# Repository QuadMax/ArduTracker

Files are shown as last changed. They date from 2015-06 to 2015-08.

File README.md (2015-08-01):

# ArduTracker

The ArduTracker is a light weight, easy to build FPV Tracker. It uses the downlink of the audio channel from the Transmitter as telemetry link. But this project is different from most others. ArduTracker is a continuous 360° degree Tracker with a special hinge. This [Video](https://vimeo.com/3991479) shows it best.

***

##[Wiki](https://github.com/QuadMax/ArduTracker/wiki) --||-- [RoadMap](https://github.com/QuadMax/ArduTracker/wiki/RoadMap)
***

###Milestone [0.9.0]
Today the compass could be implemented. This take us a step closer to a stable Version that has got all features.
The system´s components could be tested succesfully each by their own.
A whole system test comes soon.
* **This is new:**
 * implemented compass

###Milestone [0.8.1]
We are close leaving BETA! Heureka.
* **This is new:**
* The pcb design have been reworked. Now we got a groundstation that could power up 5 more devices. With 35um copper thickness it could bear 3 Ampere or 4.5 Ampere with 70um copper thickness.
* Furthermore the code got a rework too.
  * implemented cesco1´s PSK modem instead FSK
  * implemented 270 degree servos
  * implemented display / Menu / buttons
  * implemented servo invert with jumper on the uno shield

### Milestone [0.1.1]
* New pcb design with power distribution. 
  Now you could power up 3 more devices of your ground station with the pcb. Up to 2.5 Ampere. with 35um copper thickness.

### Milestone [0.1.0]
* pcb design first try

### Milestone [0.0.1]
* released Alpha

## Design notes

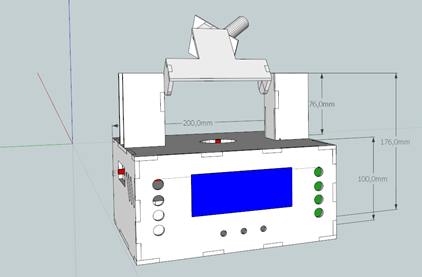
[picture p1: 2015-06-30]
Hardware/Box-all_in_one/big_box.png

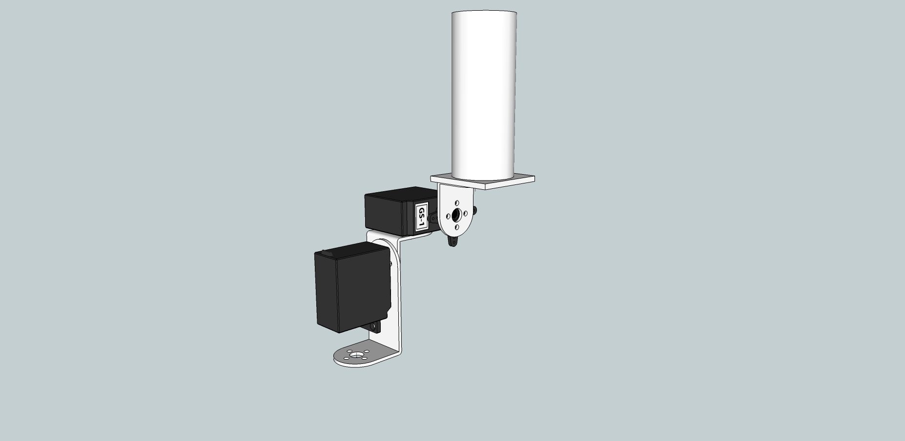
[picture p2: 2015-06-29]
Hardware/Box-minimal/tracker.jpg

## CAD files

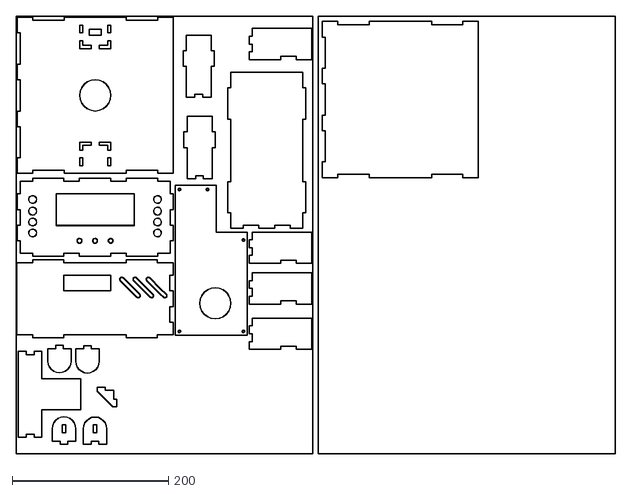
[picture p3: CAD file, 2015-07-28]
Hardware/Box-all_in_one/big_box.dxf
767.4 x 560.0

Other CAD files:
Hardware/Box-all_in_one/tracker 0.1.9.6.skp

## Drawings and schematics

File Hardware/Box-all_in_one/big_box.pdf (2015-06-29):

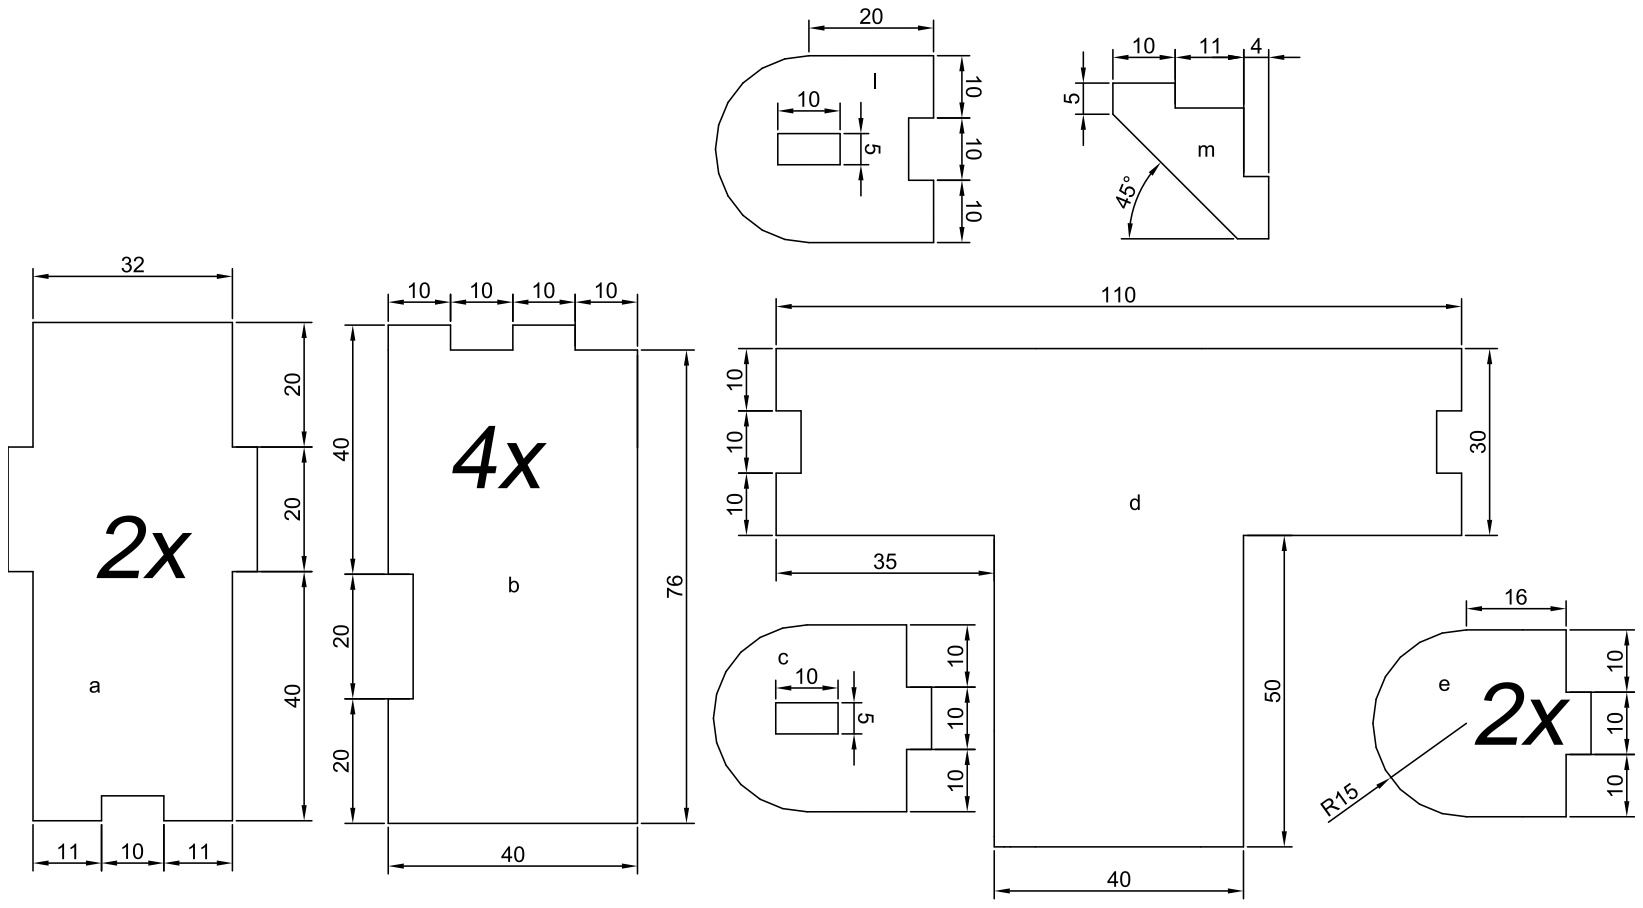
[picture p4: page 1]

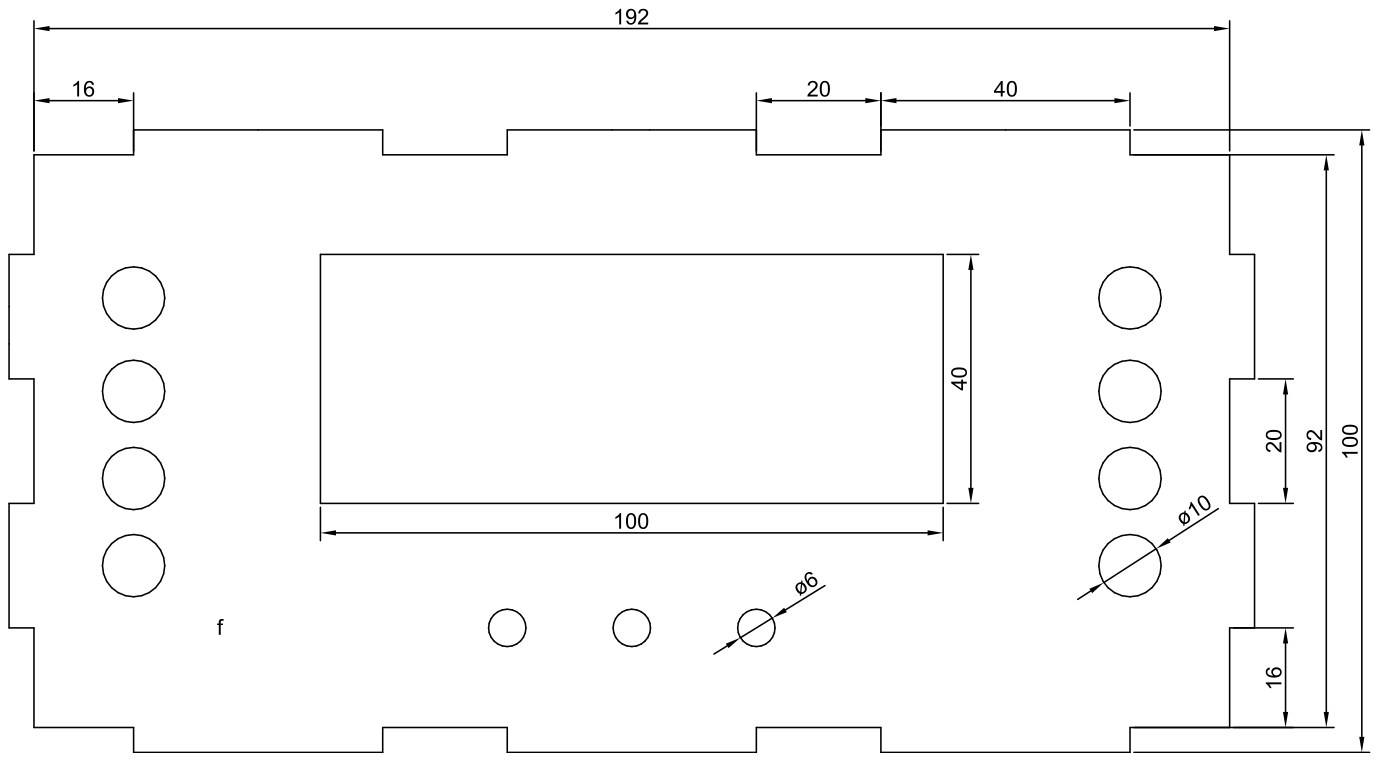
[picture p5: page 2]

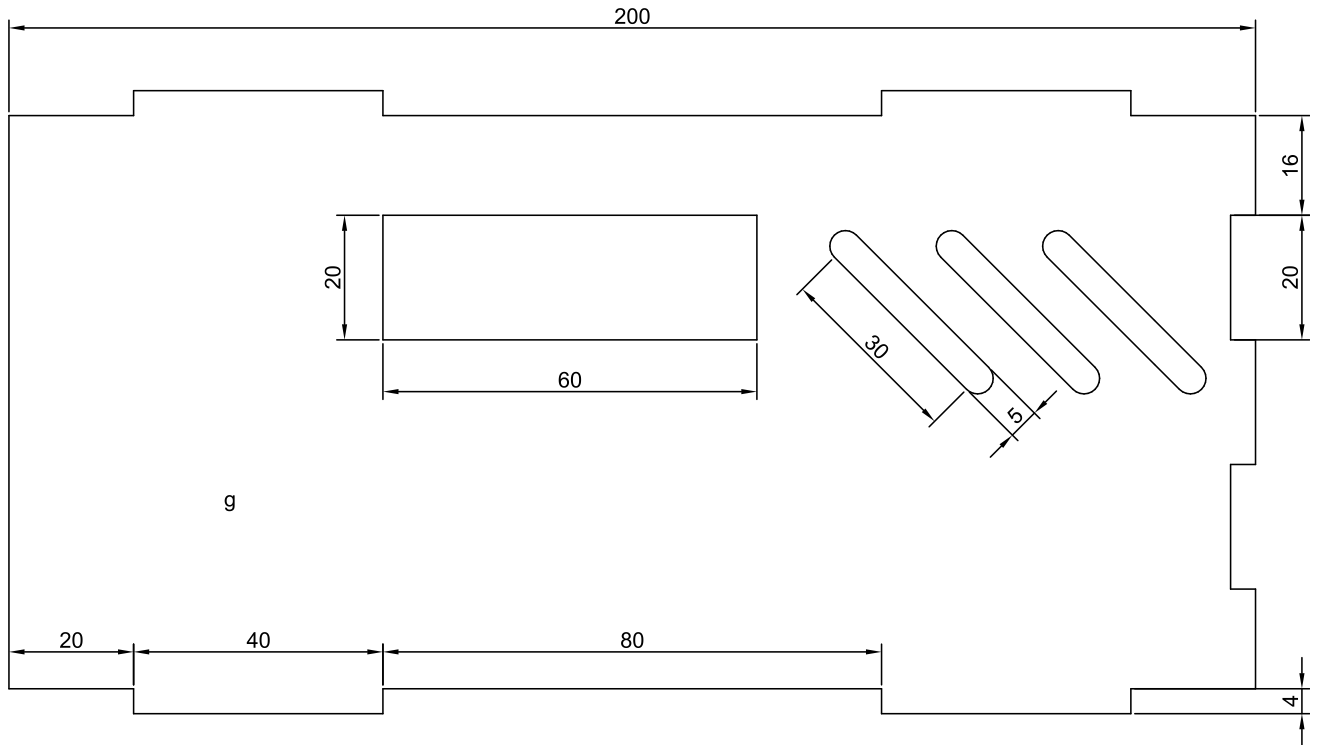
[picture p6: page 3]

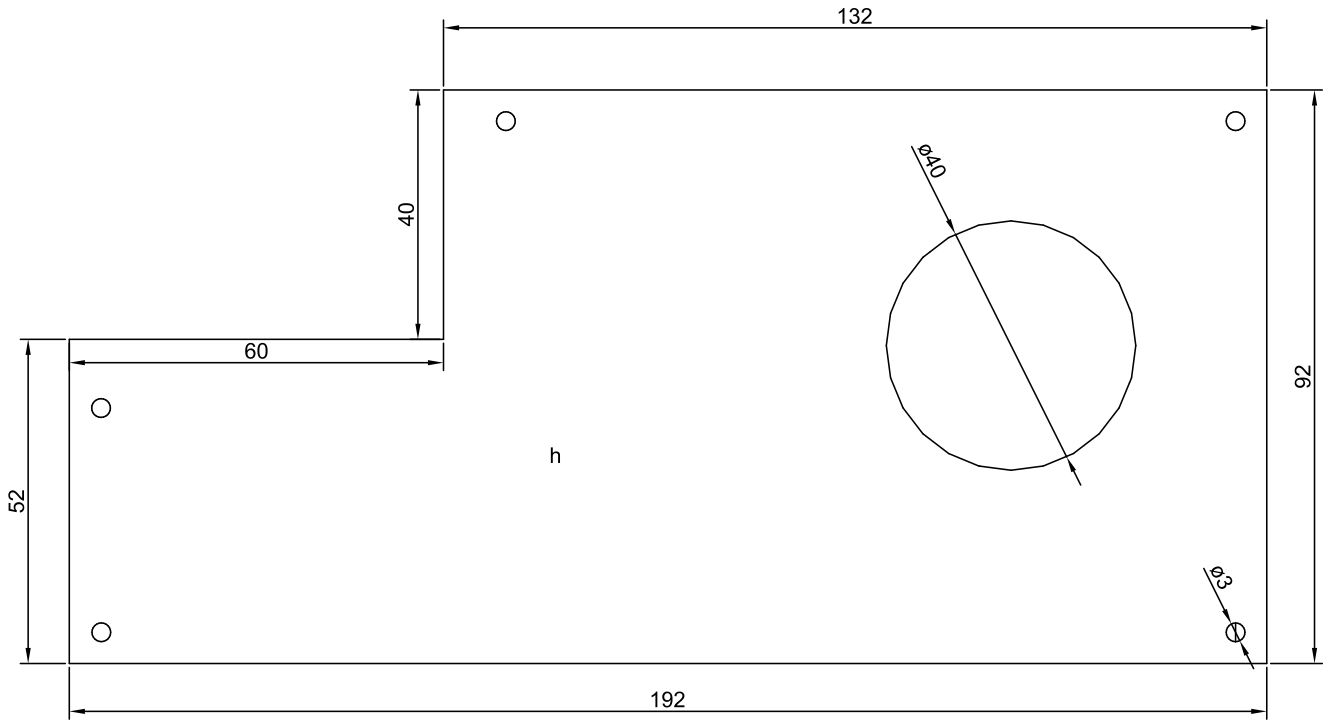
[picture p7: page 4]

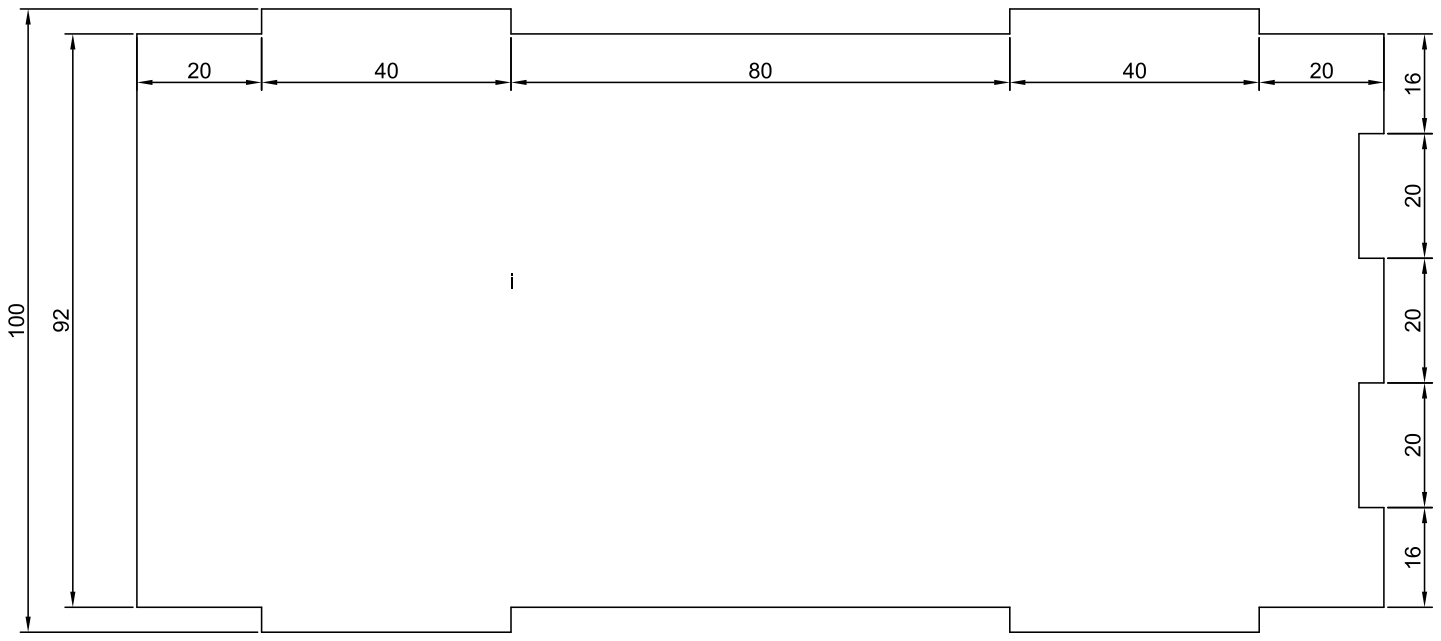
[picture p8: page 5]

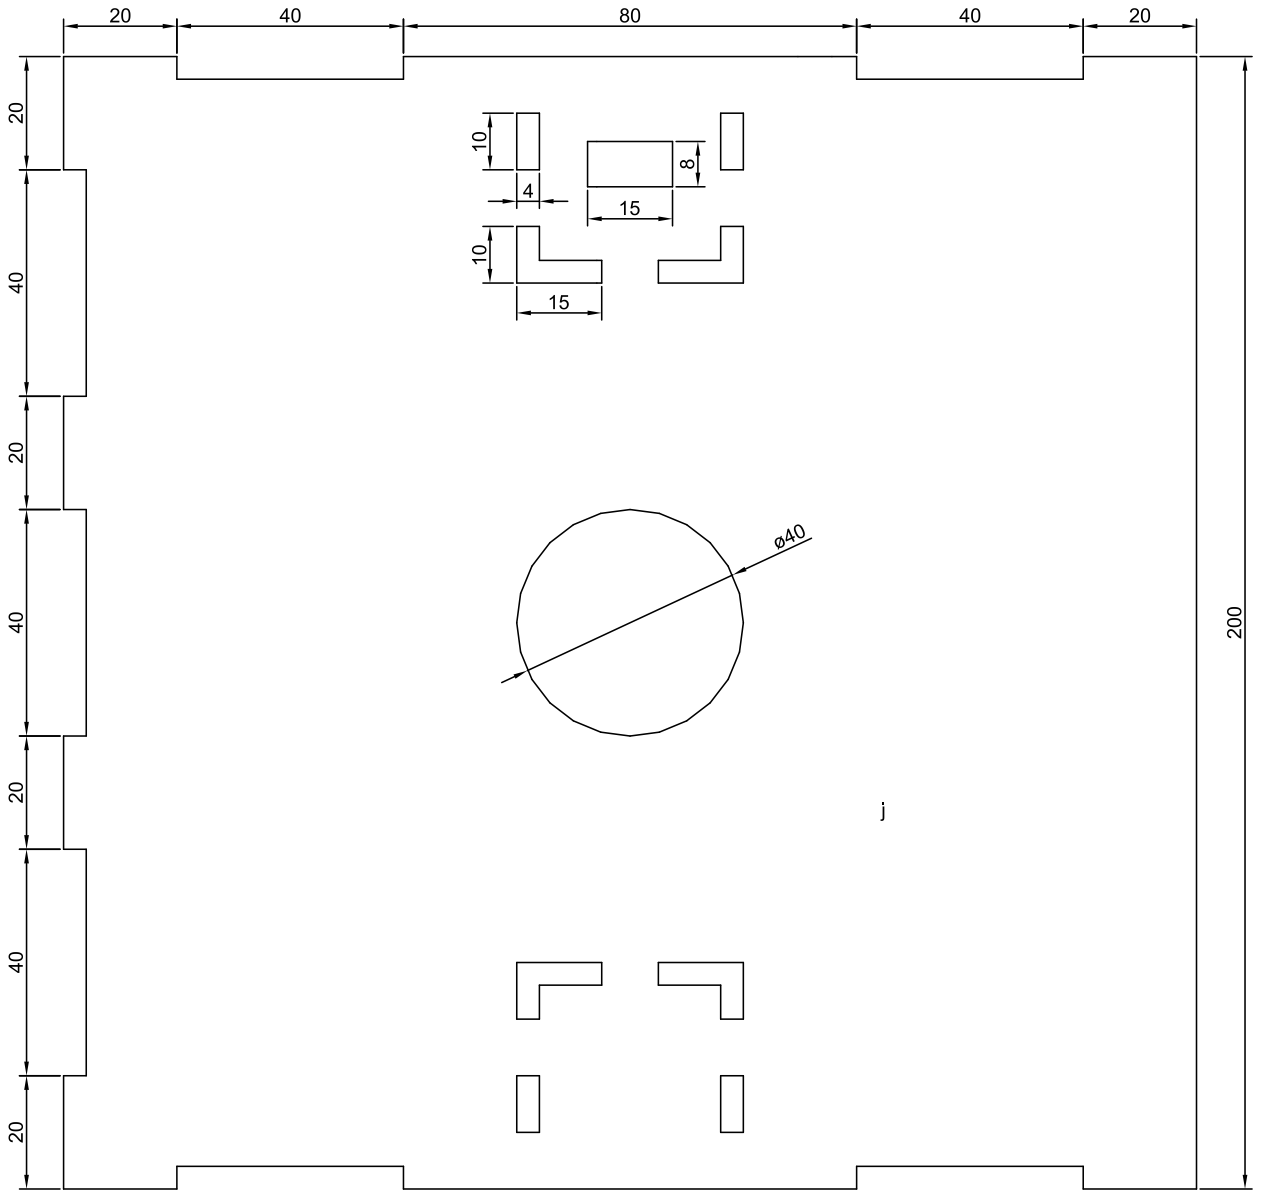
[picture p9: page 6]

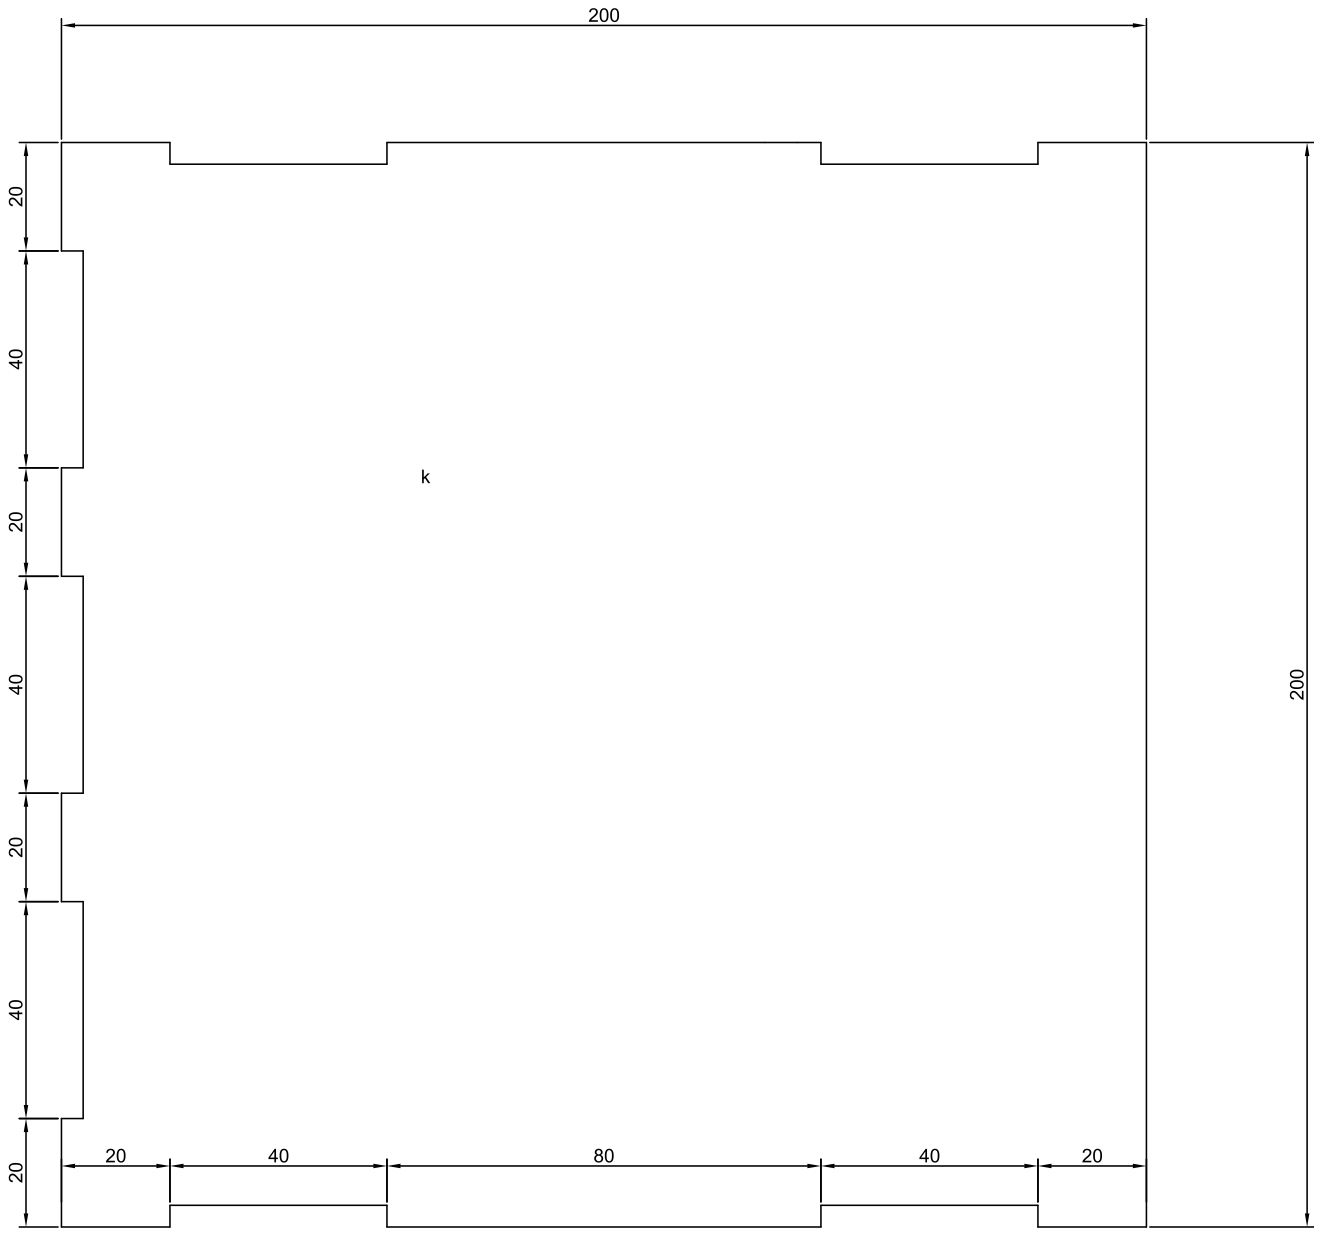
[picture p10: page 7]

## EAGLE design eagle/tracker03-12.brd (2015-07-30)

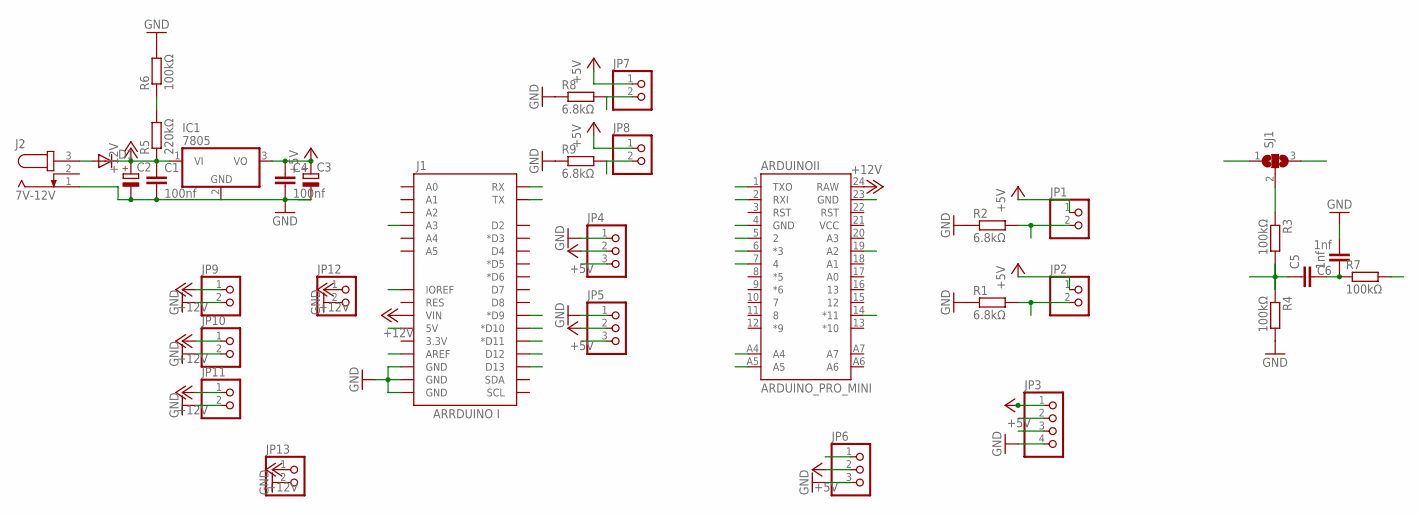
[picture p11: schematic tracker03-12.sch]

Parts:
ARDUINOII: ARDUINO_PRO_MINI
C1, C4: 100nf; C050-025X075
C2: CPOL-EUE3.5-8; E3,5-8
C3: CPOL-EUE2.5-5; E2,5-5
C5, C6: 1nf; C050-025X075
D1: 1N4004; DO41-10
IC1: 7805; TO220V
J1: ARRDUINO I; UNO_R3_SHIELD_NOLABELS
J2: 7V-12V; SPC4077
JP1, JP2, JP7, JP8, JP9, JP10, JP11, JP12, JP13: PINHD-1X2; 1X02
JP3: PINHD-1X4; 1X04
JP4, JP5, JP6: PINHD-1X3; 1X03
R1, R2, R8, R9: 6.8kΩ; 0204V
R3, R4, R6, R7: 100kΩ; 0204V
R5: 220kΩ; 0204V
SJ1: SJ2W; SJ_2

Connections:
5VA: J1.5V, SJ1.3
+5V: C3.+, C4.1, IC1.3 (VO), JP1.1, JP2.1, JP3.1, JP4.2, JP5.2, JP6.2, JP7.1, JP8.1
+12V: ARDUINOII.24 (RAW), C1.1, C2.+, D1.C, IC1.1 (VI), J1.VIN, JP9.1, JP10.1, JP11.1, JP12.1, JP13.1, R5.1
A2: ARDUINOII.19 (A2), R5.2, R6.1
A3: C5.1, J1.A3, R3.2, R4.1
A4: ARDUINOII.A4, JP3.2
A5: ARDUINOII.A5, JP3.3
AREF: J1.AREF, SJ1.1
AUDIO: R7.2
D2: ARDUINOII.5 (2), JP1.2, R2.2
D3: ARDUINOII.6 (*3)
D4: ARDUINOII.7 (4), JP2.2, R1.2
D9: J1.D9 (*D9), JP4.3
D10: J1.D10 (*D10), JP5.3
D11: ARDUINOII.14 (*11), JP6.1
D11A1: J1.D11 (*D11), JP7.2, R8.2
D12: J1.D12, JP8.2, R9.2
D13: J1.D13
GND: ARDUINOII.4 (GND), ARDUINOII.23 (GND), C1.2, C2.-, C3.-, C4.2, C6.2, IC1.2 (GND), J1.GND@0 (GND), J1.GND@1 (GND), J1.GND@2 (GND), J2.1, JP3.4, JP4.1, JP5.1, JP6.3, JP9.2, JP10.2, JP11.2, JP12.2, JP13.2, R1.1, R2.1, R4.2, R6.2, R8.1, R9.1
unnamed: D1.A, J2.3
unnamed: R3.1, SJ1.2
unnamed: C5.2, C6.1, R7.1
RX: ARDUINOII.1 (TXO), J1.RX
TX: ARDUINOII.2 (RXI), J1.TX

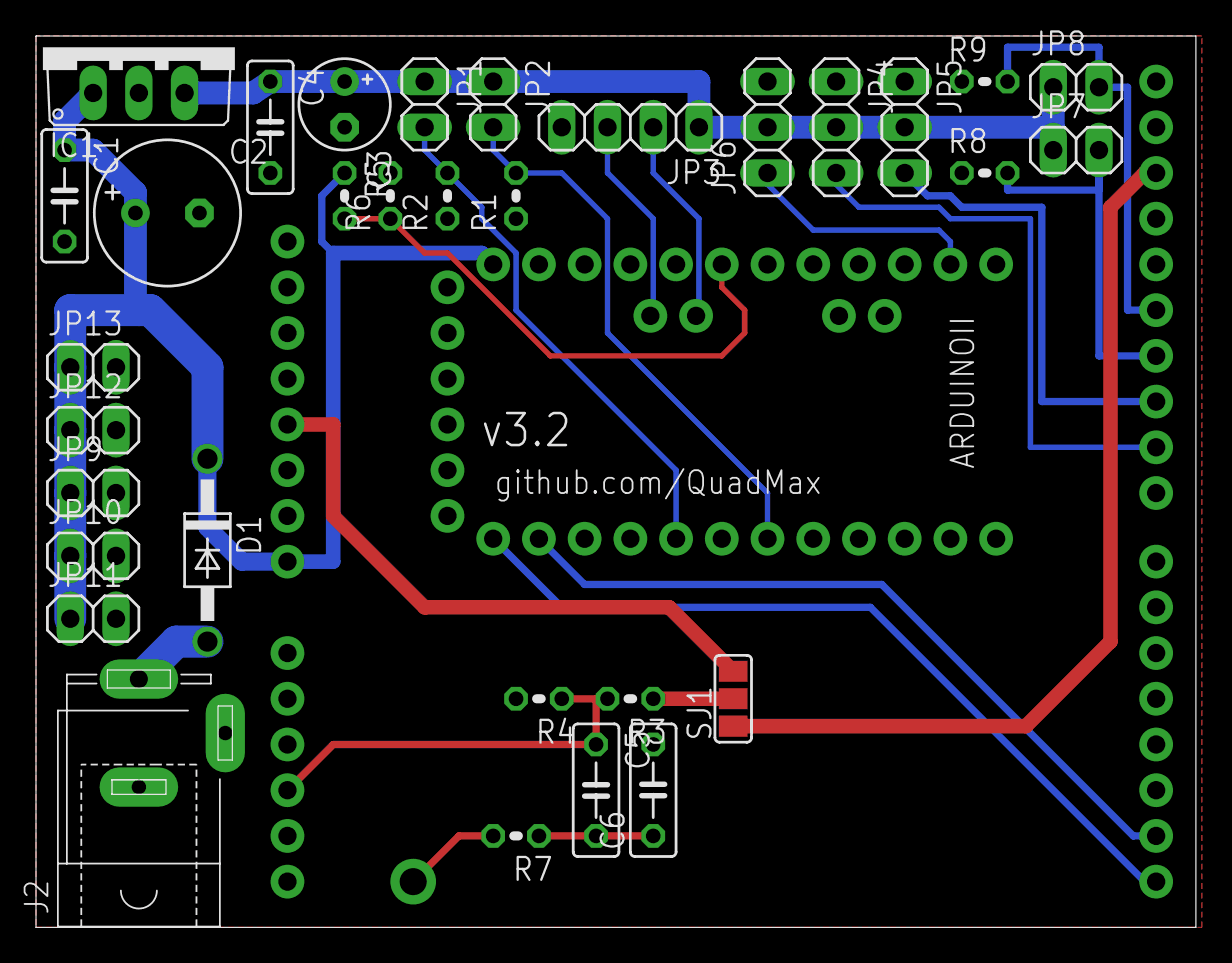
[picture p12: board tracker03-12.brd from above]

Board: 2 copper layers, 64.4 x 49.5 mm, 34 parts (0 on the bottom side), 21 nets.

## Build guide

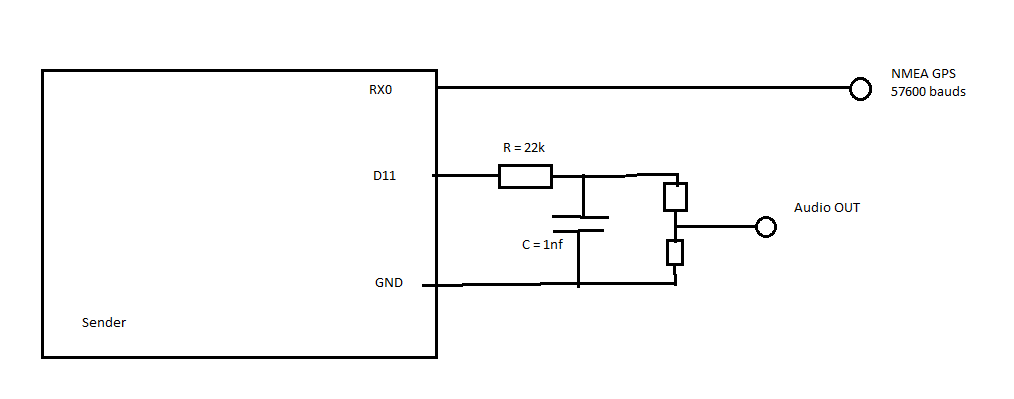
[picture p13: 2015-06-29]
wiring diagrams/transmitter.png

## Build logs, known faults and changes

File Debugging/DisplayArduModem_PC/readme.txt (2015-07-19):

Processing source

This displays an oscilloscope like view of the input. The ardumodem-RX sketch needs to be compiled with "#define TESTRXLEVEL". The input should have no offset and be in between the grey lines. Offset will absolutely destroy performance, and too small signal level will deteriorate performance.

Expect 10db SNR to work reliably.

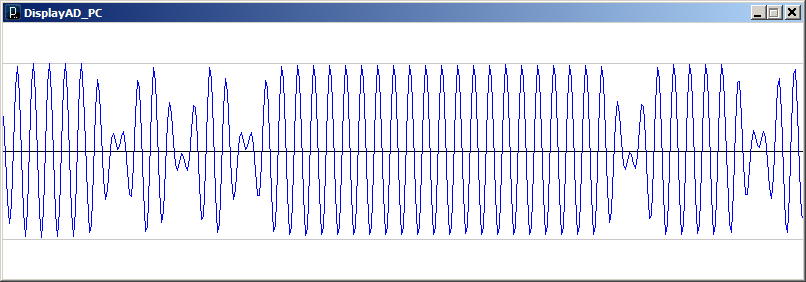
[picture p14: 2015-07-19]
Debugging/DisplayArduModem_PC/example_psk.png

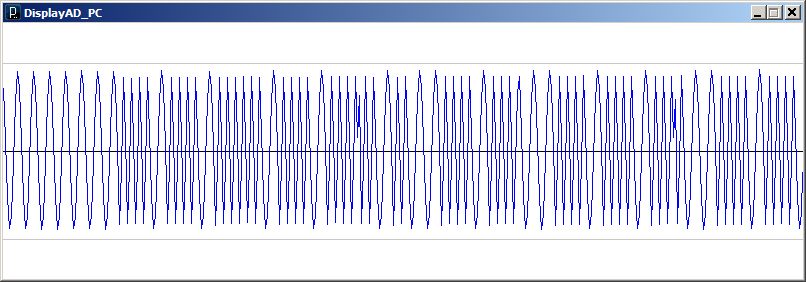
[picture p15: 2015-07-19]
Debugging/DisplayArduModem_PC/example_fsk.png

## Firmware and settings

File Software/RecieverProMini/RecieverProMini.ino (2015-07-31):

// Reference the I2C Library
#include <Wire.h>
// Reference the HMC5883L Compass Library
#include "HMC5883L.h"
#include <LiquidCrystal_I2C.h>   //see link above
#include "configuration.h"



//                    addr, en,rw,rs,d4,d5,d6,d7,bl,blpol
LiquidCrystal_I2C lcd(0x27, 2, 1, 0, 4, 5, 6, 7, 3, POSITIVE);  // Set the LCD I2C address

/*-----( Declare Variables )-----*/

int sekunde, minute, stunde, sensorValue, counter;
int crt = 0;
int K1 = 2;
int K2 = 3;
int K1read,K2read;
long TimeSetZero = 0;
long timerMenu = 0;
float voltage = 0;
int error = 0;

uint16_t headingDegrees;

HMC5883L compass;

#define lat 0
#define lon 1

int32_t  GPS_coord[2] = { 0, 0 };
uint16_t GPS_altitude;

void setup() {
  Wire.begin(); // Start the I2C interface.
  init_compass();  
  get_heading();
  delay(200); //give the UNO a chance to get started
  get_heading();
  
  SerialOpen(BAUDRATE);
  stop_compass();
  send_heading();

  
      

}

void loop() {
  
  if((millis()-1000) > timerMenu){
    //menu();
    timerMenu = millis();  
  }
}

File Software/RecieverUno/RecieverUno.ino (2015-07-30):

#include "configuration.h"


unsigned long time,lasttime;
uint16_t timediff;



float LonScale = 1.0;
float angleaz,anglel;
float sin_heading, cos_heading;

uint8_t c,i,d;

int16_t dlat;
int16_t dlon;
int16_t dalt;
int16_t heading;
int16_t GPS_heading;
int16_t diff_heading;

int32_t  GPS_coord[2] = { 0, 0 };
uint8_t  GPS_numSat;
uint16_t GPS_altitude;
uint16_t GPS_speed;

int32_t  home[2] = { 0, 0 };
int16_t  home_alt = 0;
boolean  home_set = false;
boolean tower_inv = false;
boolean arm_inv = false;
extern uint16_t servo[2];

void setup() 
{  
  pinMode(tower, INPUT);
  pinMode(arm, INPUT);  
  SerialOpen(BAUDRATE);
  get_heading();
  initPsk();
  time = millis();
  lasttime = time;

  invert_servo_jumper();
}


  

void loop() 
{

  
    if (receiveLTM())
    {
      if (!home_set)
      {
        if (GPS_numSat >= 6)
        {
          home_set  = true;
          home[lat] = GPS_coord[lat];
          home[lon] = GPS_coord[lon];
          home_alt  = GPS_altitude;
          calc_lon_scale(); 
        }
      }
           
    // calculate angles
    calcangles();
      
    // output to pan / tilt servo
    angletoservo();
    writeServos();     

    lasttime = time;
  }
    
  if (time - lasttime >= 1050) 
  {
    lasttime = time;
  }
  
}

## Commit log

2015-06-29 Version [0.0.1]
    [tracker 0.1.9.6.skp]
2015-06-30 Version [0.1.0]
    [tracker03-07.brd, tracker03-07.sch]
2015-07-18 Preparing next big milestone
    [tracker 0.1.9.6.skp]
2015-07-23 first dry
    [configuration.h]
2015-07-23 Revert "first dry"
    This reverts commit 7e4aa39fc547326ef01375a12e2c486fc155cf8f.
    [configuration.h]
2015-07-23 Revert "Revert "first dry""
    This reverts commit c0850195adbc13ca56c05269b1c6c324b066d972.
    [configuration.h]
2015-07-23 first try
    [configuration.h, tracker03-07.brd, tracker03-07.sch]
2015-07-23 major update
    [configuration.h, tracker03-09.brd, tracker03-09.sch]

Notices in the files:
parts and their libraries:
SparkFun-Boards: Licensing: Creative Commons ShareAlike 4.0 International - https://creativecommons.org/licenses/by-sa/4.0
